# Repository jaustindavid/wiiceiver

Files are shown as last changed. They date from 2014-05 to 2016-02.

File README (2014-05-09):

http://austindavid.com/t/wiiceiver-github

The Wiiceiver is a drop-in "plug and play" replacement for a
standard R/C receiver.  It has a Nintendo Wii Nunchuck 
connection, a 3-pin ESC connector, and an available connector
for an external BEC if required.  

The Wiiceiver is intended for use on an electric skateboard.
The Y-axis (up/down) is throttle -- push up to speed up,
middle is neutral, down is brakes.  These function roughly
the same as on a standard RC transmitter.

Wiiceiver also implements a few additional functions:
- X/Y joystick axes, X/Y/Z accelerometers, and the two buttons 
  are monitored to confirm that the nunchuck is "active" -- 
  as opposed to dropped or low battery.  When "inactive" the
  wiiceiver returns to neutral, and will not re-start until 
  it detects and active neutral signal
- C button is "cruise control" -- press and hold C to maintain
  the current throttle level.  Drop the joystick to neutral to
  cruise.  While holding C, pressing the joystick "up" will
  increase speed gently, "down" will decrease speed.  
  Releasing C returns to neutral.
- Control smoothing: Wiiceiver implemenets an exponential 
  algorithm to smooth the controller input.  As currently
  tuned, an instant 0-100% throttle input will result in a
  gradual change to the ESC over the course of about 1s.

It has been tested to work with a corded Nintendo nunchuck, a 
Memorex wireless nunchuck, and a Nyko Kama wireless nunchuck.

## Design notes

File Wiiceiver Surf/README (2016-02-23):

Wiiceiver Surf Chuck + Wiiceiver Surf Board is a new *pair* of things.

The Chuck is a gutted / modified Nintendo Nunchuck w/ NRF24L01+ radio; 
it can run for hours on a small LiPo battery and has better range than
the Nyko Kama wireless.

The Board is an updated "Wiiceiver" with the NRF24L01+ radio hookup, 
but no traditional nunchuck port.

Board-side functionality is similar to the traditional Wiiceiver.
Over time I will add:
- voltage sensing on the Board / display to Chuck (red/green/yellow 
  lights to indicate battery remaining)
- integrated battery control: press a button on the Board to start it,
  use the Chuck power button to shut it down.
- pairing / syncing between up to 100 Chucks & 100 Boards

The fun thing about this setup: it doesn't depend on the Nintendo
Nunchuck; it can be easily integrated into any analog controller.

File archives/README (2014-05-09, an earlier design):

"archives" of Wiiceivers past

Wiiceiver_84 was based on the ATtiny84, a 14-pin Arduino-compatible
microcontroller.  It's significantly smaller than the ATmega328,
but doesn't have hardware support for I2C or PWM.  I successfully
emulated these in software (with significant help from available
libraries) but was having trouble with the Nyko Kama, and it can't 
present both Serial output as well as I2C and PWM -- hard to debug.
SN01 == Serial Number 1, it was soldered on hardware.  Works with 
a wired chuck, but see above re: debugging the Nyko.

Wiiceiver_85 was the same, but for ATtiny85: 8 pins, but otherwise
similar to the '84.

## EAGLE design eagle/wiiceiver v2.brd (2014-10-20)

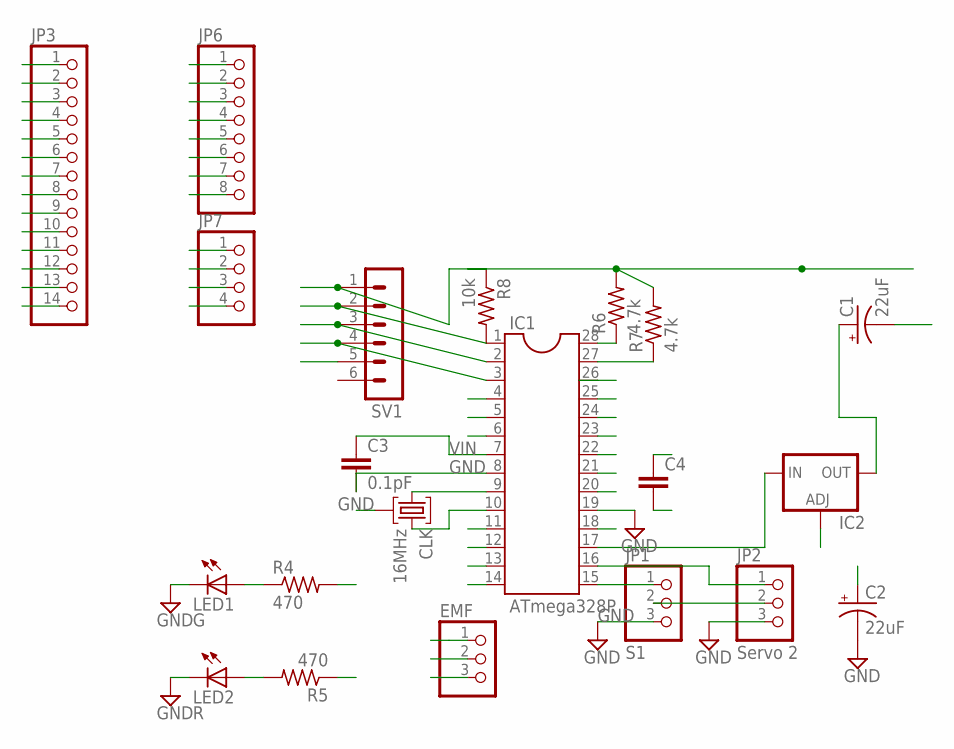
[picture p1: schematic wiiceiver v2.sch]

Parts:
C1, C2: 22uF; B45181A
C3: 0.1pF; C5B2.5
C4: C5/2.5; C5B2.5
CLK: 16MHz; HC49U
EMF: PINHD-1X3; 1X03
IC1: ATmega328P; DIL28-3
IC2: LM317TS; 317TS
JP1: S1; 1X03
JP2: Servo 2; 1X03
JP3: PINHD-1X14; 1X14
JP6: PINHD-1X8; 1X08
JP7: PINHD-1X4; 1X04
LED1: G; LED3MM
LED2: R; LED3MM
R4, R5: 470; 0204V
R6, R7: 4.7k; 0204V
R8: 10k; 0204V
SV1: MA06-1

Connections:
A0: IC1.23, JP3.6
A1: IC1.24, JP3.5
A2: IC1.25, JP3.4
A3: IC1.26, JP3.3
A4: IC1.27, JP3.2, R7.1
A5: IC1.28, JP3.1, R6.1
D0: IC1.2, JP6.2, SV1.3
D1: IC1.3, JP6.3, SV1.4
D2: IC1.4, JP6.4
D3: IC1.5, JP6.5
D4: IC1.6, JP6.6
D5: IC1.11, JP7.1
D6: IC1.12, JP7.2, R4.2
D7: IC1.13, JP7.3
D8: IC1.14, JP7.4, R5.1
D9: IC1.15, JP1.1, JP3.14
D10: IC1.16, JP2.1, JP3.13
D11: IC1.17, IC2.3 (IN), JP3.12
D12: IC1.18, JP3.11
D13: JP3.10
GND: C1.-, C2.-, C3.2, C4.2, CLK.2, EMF.2, IC1.8, IC1.19, IC1.22, IC2.1 (ADJ), JP1.3, JP2.3, JP3.7, JP6.8, LED1.K (C), LED2.K (C), SV1.5
unnamed: LED2.A, R5.2
unnamed: LED1.A, R4.1
unnamed: CLK.3, IC1.10
unnamed: CLK.1, IC1.9
unnamed: C1.+, IC2.2 (OUT)
RST: IC1.1, JP6.1, R8.2, SV1.2
VIN: C3.1, C4.1, EMF.3, IC1.7, IC1.20, IC1.21, JP3.8, JP3.9, JP6.7, R6.2, R7.2, R8.1, SV1.1
VRAW: C2.+, EMF.1, JP1.2, JP2.2

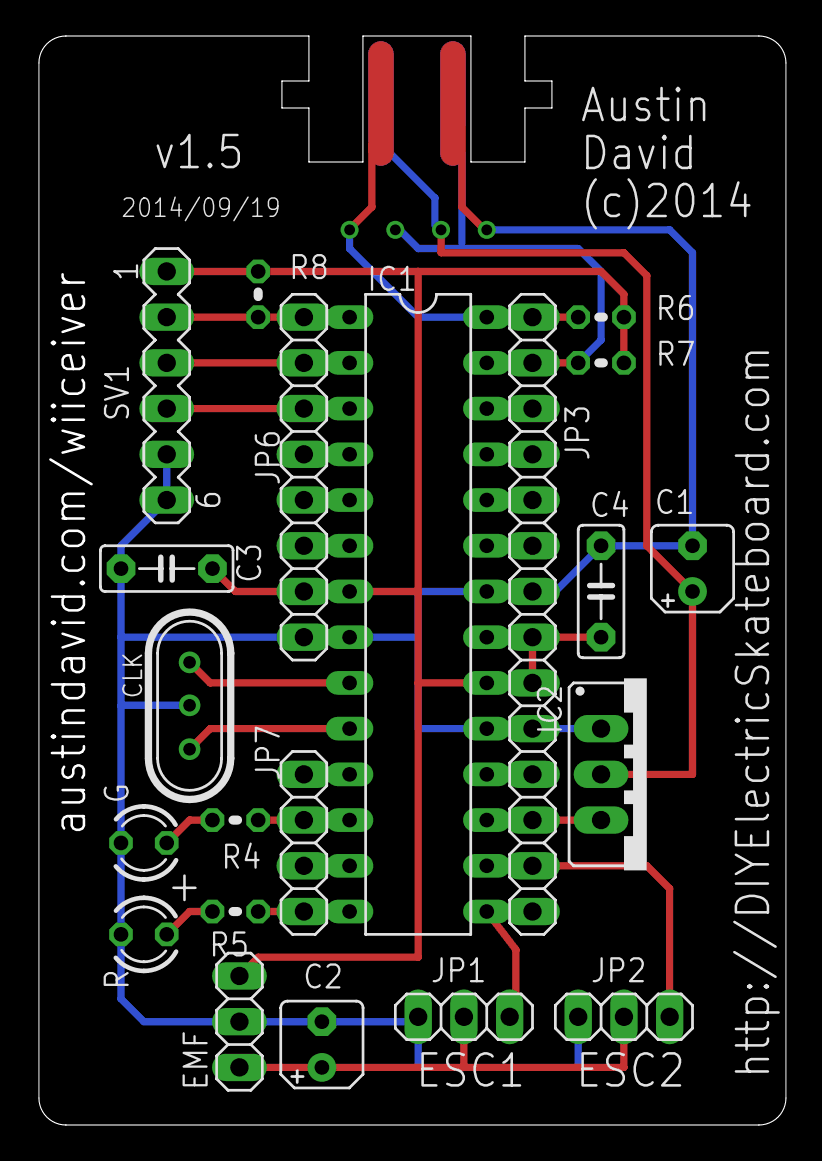
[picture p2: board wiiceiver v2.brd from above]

Board: 2 copper layers, 41.5 x 60.5 mm, 21 parts (0 on the bottom side), 28 nets.

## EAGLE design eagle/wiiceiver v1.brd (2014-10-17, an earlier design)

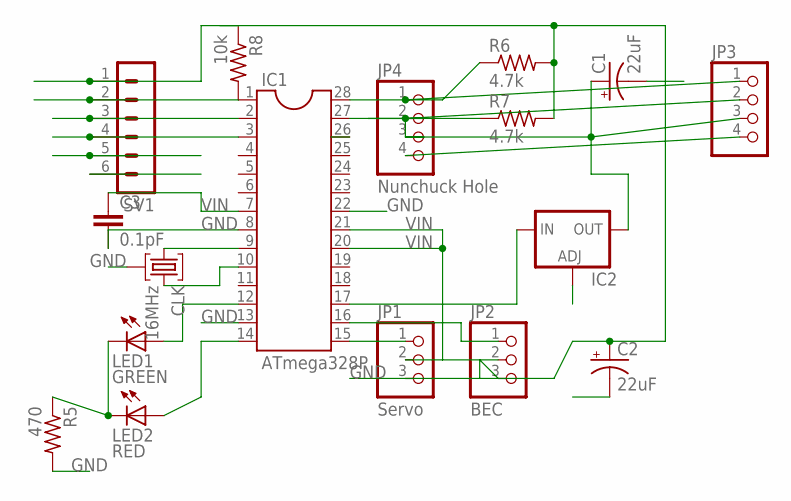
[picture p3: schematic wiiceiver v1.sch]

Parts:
C1, C2: 22uF; B45181A
C3: 0.1pF; C5B2.5
CLK: 16MHz; HC49U
IC1: ATmega328P; DIL28-3
IC2: LM317TS; 317TS
JP1: Servo; 1X03
JP2: BEC; 1X03
JP3: PINHD-1X4; 1X04
JP4: Nunchuck Hole; 1X04
LED1: GREEN; LED3MM
LED2: RED; LED3MM
R5: 470; 0204V
R6, R7: 4.7k; 0204V
R8: 10k; 0204V
SV1: MA06-1

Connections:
DIP12: IC1.12, LED1.A
GND: C1.-, C2.+, C2.-, C3.2, CLK.2, IC1.8, IC1.13, IC1.22, IC2.1 (ADJ), JP1.3, JP2.3, JP3.4, JP4.4, R5.2, R6.2, R7.2, R8.1, SV1.1, SV1.5, SV1.6
unnamed: IC1.15, JP1.1
unnamed: IC1.1, R8.2, SV1.2
unnamed: IC1.16, JP2.1
unnamed: LED1.K (C), LED2.K (C), R5.1
unnamed: IC1.14, LED2.A
unnamed: CLK.3, IC1.10
unnamed: IC1.17, IC2.3 (IN)
unnamed: CLK.1, IC1.9
unnamed: C1.+, IC2.2 (OUT), JP3.2, JP3.3, JP4.3
unnamed: IC1.28, JP3.1, JP4.1, R6.1
unnamed: IC1.27, JP4.2, R7.1
RX: IC1.2, SV1.3
TX: IC1.3, SV1.4
VIN: C3.1, IC1.7, IC1.20, IC1.21, JP1.2, JP2.2

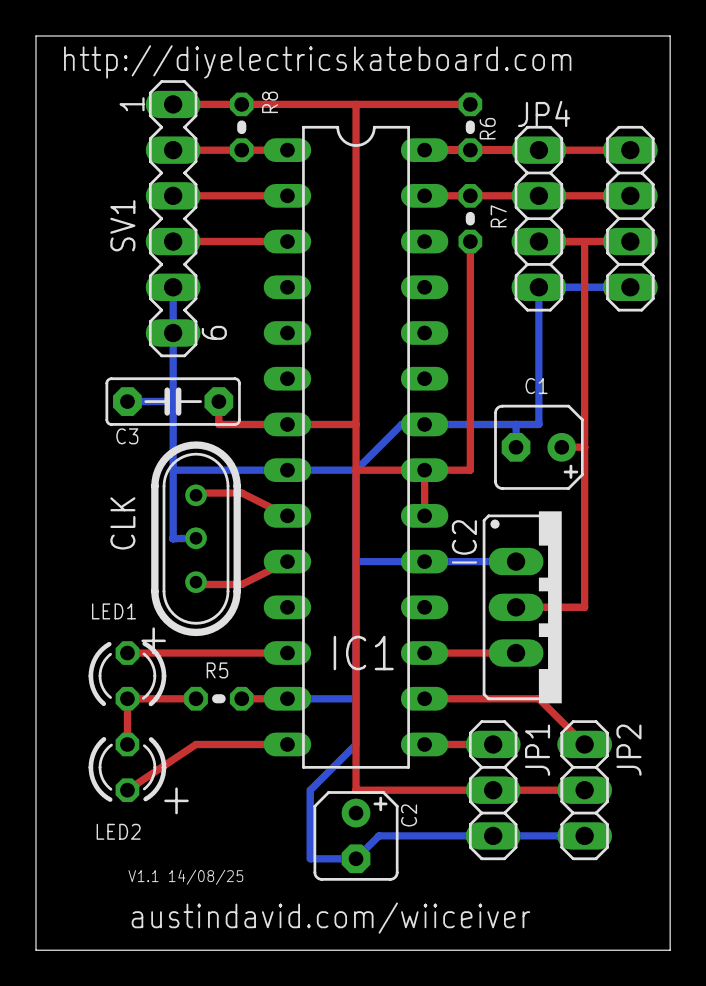
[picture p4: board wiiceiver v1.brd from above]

Board: 2 copper layers, 35.2 x 50.8 mm, 17 parts (0 on the bottom side), 16 nets.

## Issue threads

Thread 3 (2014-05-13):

faster ESC sync

jaustindavid, 2014-05-13:
wiiceiver should sync to the ESC faster.  It currently takes several seconds when the ESC is in "auto" mode.

jaustindavid, 2015-09-28:
2.0 improves flier sync

Closed 2016-05-17.

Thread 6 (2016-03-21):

can't make the motor spins correctly

shaohad, 2016-03-21:
i have this setup:
motor : turnigy 6364 213kv
battery pack 10s li-ion
esc - turnigy 120A HV - opto
wiiciver (purchased at diyelectricskateboard)
nyko nunchuk remote + usb dongle
5V battery pack instad of ubec

my issue: i benn tring all combinations , i manage to start the wiiciver , seems like it connected to remote.
but motor bips and wont spin when i press forward
i have connected same setup to simple servo tester and its working
any ideas?

jaustindavid, 2016-03-21:
What do the lights show when you start the wiiceiver?  How do you know it's connecting to the remote?

Were you able to run the setup routine?

shaohad, 2016-03-21:
how can we speak directly?
skype? so i could show you a video?
my email is shaohad@gmail.com

jaustindavid, 2016-03-21:
email the video to austin@austindavid.com

shaohad, 2016-03-21:
email sent

Closed 2016-05-17.

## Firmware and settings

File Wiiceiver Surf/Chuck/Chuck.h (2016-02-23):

/*
 * (CC BY-NC-SA 4.0) 
 * http://creativecommons.org/licenses/by-nc-sa/4.0/
 *
 * WARNING WARNING WARNING: attaching motors to a skateboard is 
 * a terribly dangerous thing to do.  This software is totally
 * for amusement and/or educational purposes.  Don't obtain or
 * make a wiiceiver (see below for instructions and parts), 
 * don't attach it to a skateboard, and CERTAINLY don't use it
 * to zip around with just a tiny, ergonomic nunchuck instead
 * of a bulky R/C controller.
 *
 * This software is made freely available.  If you wish to 
 * sell it, don't.  If you wish to modify it, DO! (and please
 * let me know).  Much of the code is derived from others out
 * there, I've made attributuions where appropriate.
 *
 * http://austindavid.com/wiiceiver
 *  
 * latest software: https://github.com/jaustindavid/wiiceiver
 * schematic & parts: http://www.digikey.com/schemeit#t9g
 *
 * Enjoy!  Be safe! 
 * 
 * (CC BY-NC-SA 4.0) Austin David, austin@austindavid.com
 * 12 May 2014
 *
 */
 
#ifndef CHUCK_H
#define CHUCK_H

/*
 *  A "tiny" Wii Nunchuck class
 *  Borrows heavily from:
 *
 *   Nunchuck -- Use a Wii Nunchuck
 *   Tim Hirzel http://www.growdown.com
 * who cites:
 *
 * * This file is an adaptation of the code by these authors:
 * Tod E. Kurt, http://todbot.com/blog/
 *
 * The Wii Nunchuck reading code is taken from Windmeadow Labs
 * http://www.windmeadow.com/node/42
 *
 * Conversion to Arduino 1.0 by Danjovic
 * http://hotbit.blogspot.com
 *
 * Included the Fix from Martin Peris by Leopold Klimesch
 * http://blog.martinperis.com/2011/04/arduino-wiichuck.html
 *
 *
 * Taking all of the above into account, this class is heavily adapted
 * for the specific usage here: a single-channel (~1.5), activity-sensitive 
 * controller for an electric skateboard.  I've deliberately removed or not used
 * a fair amount of the data available from the 'chuck, in the interest of 
 * keeping memory down for the ATtiny series.
 *
 */
class Chuck {
#ifndef WII_ACTIVITY_COUNTER
#define WII_ACTIVITY_COUNTER 250  // consecutive static reads & it's considered inactive
#endif
#define DEFAULT_Y_ZERO 128
#define DEFAULT_X_ZERO 128

private:
  byte lastStatus[6];
  byte Y0, Ymin, Ymax, X0, Xmin, Xmax;
  word lastActivity, activitySamenessCount;
public:
  byte status[6];
  float X, Y;
  bool C, Z;


private:

  bool all255s(void) {
    for (int i=0; i < 6; i++) {
      if (status[i] != 255) {
        return false;
      }
    }
    return true;
  } // bool all255s(void)


  bool statusChanged(void) {
    for (int i=0; i < 6; i++) {
      if (status[i] != lastStatus[i]) {
        return true;
      }
    }
    
    return false;
  } // bool statusChanged()
  
  
  void saveLastStatus(void) {
    for (int i=0; i < 6; i++) {
      lastStatus[i] = status[i];
    }
  } // void saveLastStatus()

  
  // tracks the max-observed deflection (high & low)
  void _selfCalibrateDeflection(void) {
    byte joyX = status[0];
    Xmin = min(joyX, Xmin);
    Xmax = max(joyX, Xmax);
 
    byte joyY = status[1];

    if (joyY < Ymin) {
      Ymin = joyY;
    }

    if (joyY > Ymax) {
      Ymax = joyY;
    }
  } // void _selfCalibrateDeflection(void)


  void _computeStatus(void) {
    byte joyX = status[0];
    byte joyY = status[1];
    _selfCalibrateDeflection();
    
    int centeredX = joyX - X0;
    if (centeredX == 0) {
      X = 0;
    } 
    else if (centeredX > 0) {
      X = 1.0 * centeredX / (Xmax - X0);
    } 
    else {
      X = -1.0 * centeredX / (Xmin - X0); 
    }
    
    int centeredY = joyY - Y0;
    if (centeredY == 0) {
      Y = 0;
    } 
    else if (centeredY > 0) {
      Y = 1.0 * centeredY / (Ymax - Y0);
    } 
    else {
      Y = -1.0 * centeredY / (Ymin - Y0); 
    }

    C = ((status[5] & B00000010) >> 1) == 0;
    Z = (status[5] & B00000001) == 0;


    if (!statusChanged()) { 
      if (activitySamenessCount < WII_ACTIVITY_COUNTER) {
        activitySamenessCount ++;
      }
    } else {
      activitySamenessCount = 0;
      saveLastStatus();
    }
    
#ifdef DEBUGGING_CHUCK_ACTIVITY
    Serial.print(F("CHUCK: "));
    for (int i = 0; i < 5; i++) {
      Serial.print(F(" ["));
      Serial.print(status[i], DEC);
      Serial.print(F("]"));
    }
    Serial.print(F("; sameness "));
    Serial.print(activitySamenessCount);    
    Serial.println();
#endif


  } // _computeStatus(void)


public:


  void calibrateCenter() {
    Y0 = status[1];
  } // calibrateCenter()


  // setup the nunchuck -- send the initialization sequence & start reading data
  void setup(void) {
    X0 = Y0 = 128;
    Xmin = Ymin = 15;
    Xmax = Ymax = 200;

#ifdef DEBUGGING_CHUCK
    Serial.print(millis());
    Serial.print(F(": Chuck.setup() ..."));
#endif
    Wire.begin();
    Wire.beginTransmission(0x52);       // device address
    Wire.write(0xF0);
    Wire.write(0x55);
    Wire.endTransmission();
    delay(1);
    Wire.beginTransmission(0x52);
    Wire.write(0xFB);
    Wire.write((uint8_t)0x00);
    Wire.endTransmission();
#ifdef DEBUGGING_CHUCK
    Serial.print(F(" transmitted @ "));
    Serial.print(millis());
#endif

    // do enough updates to prime the activity checker ...
    for (int i = 0; i < WII_ACTIVITY_COUNTER; i++) {
      update();
      delay(1);
    }
    
 #ifdef DEBUGGING_CHUCK
    Serial.print(F("; setup complete @ "));
    Serial.println(millis());
#endif   
  } // void setup(void)


  // update the status[] fields from the nunchuck
  void update(void) {
    // TODO: estimate the actual delay required between the request 
    // & data available on bus
    // delay(1);

    // read 6 bytes
    Wire.requestFrom (0x52, 6); // request data from nunchuck
    int cnt = 0;
    while (Wire.available()) {
      status[cnt] = Wire.read();
      cnt++;
    }

    _computeStatus();
#ifdef DEBUGGING_CHUCK_ACTIVITY
   Serial.print(F("Active? "));
   Serial.println(isActive() ? F("yes") : F("no"));
#endif

    // send one 0 to initiate transfer
    Wire.beginTransmission(0x52); 
    Wire.write(0);         
    Wire.endTransmission();

  } // void update(void)


  // is the controller "active" -- being held by a human & reporting
  // changing values?
  bool isActive(void) {
    return activitySamenessCount < WII_ACTIVITY_COUNTER && ! all255s();
  } // bool isActive(void)

};

#endif

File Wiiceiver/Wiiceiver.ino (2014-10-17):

/*
 * (CC BY-NC-SA 4.0) 
 * http://creativecommons.org/licenses/by-nc-sa/4.0/
 *
 * WARNING WARNING WARNING: attaching motors to a skateboard is 
 * a terribly dangerous thing to do.  This software is totally
 * for amusement and/or educational purposes.  Don't obtain or
 * make a wiiceiver (see below for instructions and parts), 
 * don't attach it to a skateboard, and CERTAINLY don't use it
 * to zip around with just a tiny, ergonomic nunchuck instead
 * of a bulky R/C controller.
 *
 * This software is made freely available.  If you wish to 
 * sell it, don't.  If you wish to modify it, DO! (and please
 * let me know).  Much of the code is derived from others out
 * there, I've made attributuions where appropriate.
 *
 * http://austindavid.com/wiiceiver
 *  
 * latest software: https://github.com/jaustindavid/wiiceiver
 * schematic & parts: http://www.digikey.com/schemeit#t9g
 *
 * Enjoy!  Be safe! 
 * 
 * (CC BY-NC-SA 4.0) Austin David, austin@austindavid.com
 * 12 May 2014
 *
 */

#include <avr/wdt.h> 
#include <Wire.h>
#include <Servo.h>
#include <EEPROM.h>

#define WIICEIVER_VERSION "1.2.2"

// addys for vars stored in EEPROM
#define EEPROM_Y_ADDY 0
#define EEPROM_AUTOCRUISE_ADDY 1
#define EEPROM_WDC_ADDY 2


#define DEBUGGING

#include "Blinker.h"


// #define DEBUGGING_CHUCK
// #define DEBUGGING_CHUCK_ACTIVITY
#define WII_ACTIVITY_COUNTER 100  // once per 20ms; 50 per second
#include "Chuck.h"


// #define DEBUGGING_ESC
#include "ElectronicSpeedController.h"


// #define DEBUGGING_SMOOTHER
#define SMOOTHER_MIN_STEP 0.003           // minimum change for smoothing; 0.003 for ~1s, 0.001 for ~2s
#define SMOOTHER_BRAKES_PROGRAM 0
#define SMOOTHER_THROTTLE_PROGRAM 1
#define SMOOTHER_THROTTLE_Z_PROGRAM 2
#define SMOOTHER_CRUISE_RESUME_PROGRAM 3
#include "Smoother.h"


// #define DEBUGGING_THROTTLE
#define THROTTLE_MIN 0.05                      // the lowest throttle to send the ESC
#define THROTTLE_CC_BUMP 0.003                 // CC = 0.2% throttle increase; 50/s = 10s to hit 100% on cruise
#define THROTTLE_MIN_CC 0.05                   // minimum / inital speed for cruise crontrol
                                               // note that a different value may be stored in EEPROM
#define THROTTLE_CRUISE_RETURN_MS 5000         // time (ms) when re-grabbing cruise will use the previous CC level
#include "Throttle.h"


// #define DEBUGGING_PINS
#include "pinouts.h"


Chuck chuck;
ElectronicSpeedController ESC;
Blinker green, red;
Throttle throttle;


/********
 *  WATCHDOG STUFF
 * I referenced the following:
 * http://forum.arduino.cc/index.php?topic=63651.0
 * http://tushev.org/articles/arduino/item/46-arduino-and-watchdog-timer
 * http://www.ivoidwarranties.com/2012/02/arduino-mega-optiboot.html
 *
 ********/
 
/*
 * setup a watchdog timer for the given reset interval
 *
 * constants: WDTO_250MS, WDTO_8S, WDTO_60MS, etc
 */
void watchdog_setup(byte wd_interval) {
  wdt_reset();
  wdt_enable(wd_interval);
  cli();
  WDTCSR |= (1<<WDCE) | (1<<WDE) | (1<<WDIE); 
  sei();
} // watchdog_setup(unsigned int wd_interval)


// increment a _W_atch _D_og _C_ounter stored in EEPROM, for future debugging
ISR(WDT_vect) {
  byte wdt_counter = EEPROM.read(EEPROM_WDC_ADDY);
  EEPROM.write(EEPROM_WDC_ADDY, wdt_counter + 1);
} // ISR for the watchdog timer

// display the current watchdog counter
void display_WDC(void) {
  byte wdt_counter = EEPROM.read(EEPROM_WDC_ADDY);
  Serial.print("Watchdog Resets: ");
  Serial.println((byte)(wdt_counter + 1));
} // display_WDC()



// maybe calibrate the joystick:
//   read the C button 250 times, once per 20ms (5s total); if it's constantly
//   down, calibrate the joystick
void maybeCalibrate(void) {
  int ctr = 0;
  int i = 0;

  for (i = 0; i < 10; i++) {
    chuck.update();
    delay(10);
  }
  if (chuck.C != 1 || ! chuck.isActive()) {
    return;
  }

  red.update(10);
  green.update(10);
  i = 0;
  #define C_COUNT 50
  while (i <= C_COUNT && chuck.C) {
    chuck.update();
    red.run();
    green.run();
    i++;
    ctr += chuck.C;
    delay(20);
  }

  #ifdef DEBUGGING
  Serial.print("C ctr = ");
  Serial.println(ctr);
  #endif

  if (ctr >= C_COUNT && chuck.isActive()) {
    chuck.calibrateCenter();
    chuck.writeEEPROM();
    // side effect: reset the WDC
    EEPROM.write(EEPROM_WDC_ADDY, 255);
    Serial.println("Calibrated");
  }

  red.update(1);
  green.update(1);
} // void maybeCalibrate() 

\
// an unambiguous startup display
void splashScreen() {
  int i;
  digitalWrite(pinLocation(GREEN_LED_ID), HIGH);
  digitalWrite(pinLocation(RED_LED_ID), HIGH);
  delay(250);
  for (i = 0; i < 5; i++) {
    digitalWrite(pinLocation(GREEN_LED_ID), HIGH);
    digitalWrite(pinLocation(RED_LED_ID), LOW);
    delay(50);
    digitalWrite(pinLocation(GREEN_LED_ID), LOW);
    digitalWrite(pinLocation(RED_LED_ID), HIGH);
    delay(50);
  }
  digitalWrite(pinLocation(GREEN_LED_ID), HIGH);
  digitalWrite(pinLocation(RED_LED_ID), HIGH);
  delay(250);
  digitalWrite(pinLocation(GREEN_LED_ID), LOW);    
  digitalWrite(pinLocation(RED_LED_ID), LOW);  
} // void splashScreen(void)


// flash the LEDs to indicate throttle position
void updateLEDs(Throttle throttle) {
  if (throttle.getThrottle() == 0) {
    green.update(1);
    red.update(1);
  } else {
    int bps = abs(int(throttle.getThrottle() * 20));

    if (throttle.getThrottle() > 0) {
      green.update(bps);
      red.update(1);
    } else {
      green.update(1);
      red.update(bps);
    }
  }
} // updateLEDs(float throttle)


// the nunchuck appears to be static: we lost connection!
// go "dead" for up to 5s, but keep checking the chuck to see if
// it comes back
void freakOut(void) {
  unsigned long targetMS = millis() + 5000;
  bool redOn = false;
  byte blinkCtr = 0;

#ifdef DEBUGGING
    Serial.print(millis());
    Serial.println(": freaking out");
#endif

  red.stop();
  green.stop();
  while (!chuck.isActive() && targetMS > millis()) {
//  while (targetMS > millis()) {
    if (blinkCtr >= 4) {
      blinkCtr = 0;
      if (redOn) {
        red.high();
        green.low();
        redOn = false;
      } 
      else {
        red.low();
        green.high();
        redOn = true;
      }
    }
    blinkCtr ++;
    chuck.update();
    delay(20);
    wdt_reset();
  }
  green.start(1);
  red.start(1);
} // void freakOut(void)



void setup_pins() {
  /*
  pinMode(ESC_GROUND, OUTPUT);
  digitalWrite(ESC_GROUND, LOW);
  pinMode(WII_GROUND, OUTPUT);
  digitalWrite(WII_GROUND, LOW);
  */
  pinMode(pinLocation(WII_POWER_ID), OUTPUT);
  digitalWrite(pinLocation(WII_POWER_ID), HIGH);
  
  pinMode(pinLocation(WII_SCL_ID), INPUT_PULLUP);
  pinMode(pinLocation(WII_SDA_ID), INPUT_PULLUP);

} // setup_pins()


// wait up to 1s for something to happen
bool waitForActivity(void) {
  unsigned long timer = millis() + 1000;
#ifdef DEBUGGING
    Serial.print(millis());
    Serial.print(" Waiting for activity ... ");
#endif
  
  chuck.update();
  while (! chuck.isActive() && timer > millis()) {
    wdt_reset();
    delay(20);
    chuck.update();
  }
#ifdef DEBUGGING
    Serial.print(millis());
    Serial.println(chuck.isActive() ? ": active!" : ": not active :(");
#endif
  
  return chuck.isActive();
} // bool waitForActivity()


// dead code?
void stopChuck() {
#ifdef DEBUGGING
    Serial.println("Nunchuck: power off");
#endif
  digitalWrite(pinLocation(WII_POWER_ID), LOW);
  delay(250);
#ifdef DEBUGGING
    Serial.println("Nunchuck: power on");
#endif
  digitalWrite(pinLocation(WII_POWER_ID), HIGH);
  delay(250);
} // stopChuck()



// returns true if the chuck appears "active"
// will retry 5 times, waiting 1s each
bool startChuck() {
  int tries = 0;
  
  while (tries < 10) {
#ifdef DEBUGGING
    Serial.print("(Re)starting the nunchuck: #");
    Serial.println(tries);
#endif
    wdt_reset();
    chuck.setup();
    chuck.readEEPROM();
    tries ++;
    if (waitForActivity()) {
      return true;
    }
  }
  return false;
} // startChuck()


// pretty much what it sounds like
void handleInactivity() {
  watchdog_setup(WDTO_8S);
#ifdef DEBUGGING
  Serial.print(millis());
  Serial.println(": handling inactivity");
#endif
  // lastThrottle = 0; // kills cruise control
  // smoother.zero();  // kills throttle history
  throttle.zero();
  ESC.setLevel(0);
  
  // this loop: try to restart 5 times in 5s; repeat until active
  do {    
    freakOut();
    if (! chuck.isActive()) {
      // stopChuck();
      // delay(250);
      startChuck();
    }
  } while (! chuck.isActive());
  
  // active -- now wait for zero
#ifdef DEBUGGING
  Serial.print(millis());
  Serial.println("Waiting for 0");
#endif  
  while (chuck.Y > 0.1 || chuck.Y < -0.1) {
    chuck.update();
    wdt_reset();
    delay(20);
  }
  
#ifdef DEBUGGING
  Serial.print(millis());
  Serial.println(": finished inactivity -- chuck is active");
#endif
  watchdog_setup(WDTO_250MS);
} // handleInactivity()




void setup() {
  wdt_disable();
  Serial.begin(115200);

  Serial.print("Wiiceiver v ");
  Serial.print(WIICEIVER_VERSION);
  Serial.print(" (compiled ");
  Serial.print(__DATE__);
  Serial.print(" ");
  Serial.print(__TIME__);
  Serial.println(")");
  display_WDC();
  
  green.init(pinLocation(GREEN_LED_ID));
  red.init(pinLocation(RED_LED_ID));

  setup_pins();
  ESC.init(pinLocation(ESC_PPM_ID), pinLocation(ESC2_PPM_ID));
  
  splashScreen();

  // delay(5000); // hold for nunchuck powerup

#ifdef DEBUGGING
  Serial.println("Starting the nunchuck ...");
#endif
  green.high();
  red.high();
  if (startChuck()) {
    maybeCalibrate();
  } else {
    handleInactivity();
  }
#ifdef DEBUGGING
  Serial.println("Nunchuck is active!");
#endif

  throttle.init();

  green.start(10);
  red.start(10);
  
  green.update(1);
  red.update(1);
  watchdog_setup(WDTO_250MS);
} // void setup()



void loop() {
  static float lastThrottleValue = 0;
  unsigned long startMS = millis();
  wdt_reset();
  green.run();
  red.run();
  chuck.update();
  
  // for forcing a watchdog timeout
  #undef SUICIDAL_Z
  #ifdef SUICIDAL_Z
  if (chuck.Z) {
    Serial.println("sleepin' to reset");
    delay(9000);
  } // suicide!
  
  
  #endif 
  if (!chuck.isActive()) {
#ifdef DEBUGGING
    Serial.println("INACTIVE!!");
#endif
    handleInactivity();
  } else {
    float throttleValue = throttle.update(chuck);
    ESC.setLevel(throttleValue);
    if (throttleValue != lastThrottleValue) {
      updateLEDs(throttle);
#ifdef DEBUGGING
      Serial.print("y=");
      Serial.print(chuck.Y, 4);
      Serial.print(", ");
      Serial.print("c=");
      Serial.print(chuck.C);      
      Serial.print(", z=");
      Serial.print(chuck.Z);
      Serial.print(", ");
      Serial.println(throttleValue, 4); 
#endif
      lastThrottleValue = throttleValue;
    }
    int delayMS = constrain(startMS + 21 - millis(), 5, 20);
#ifdef DEBUGGING_INTERVALS
    Serial.print("sleeping "); 
    Serial.println(delayMS);
#endif
    delay(delayMS);
  } // if (chuck.isActive())
}

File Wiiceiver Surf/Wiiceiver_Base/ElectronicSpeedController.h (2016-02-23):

/*
 * (CC BY-NC-SA 4.0) 
 * http://creativecommons.org/licenses/by-nc-sa/4.0/
 *
 * WARNING WARNING WARNING: attaching motors to a skateboard is 
 * a terribly dangerous thing to do.  This software is totally
 * for amusement and/or educational purposes.  Don't obtain or
 * make a wiiceiver (see below for instructions and parts), 
 * don't attach it to a skateboard, and CERTAINLY don't use it
 * to zip around with just a tiny, ergonomic nunchuck instead
 * of a bulky R/C controller.
 *
 * This software is made freely available.  If you wish to 
 * sell it, don't.  If you wish to modify it, DO! (and please
 * let me know).  Much of the code is derived from others out
 * there, I've made attributuions where appropriate.
 *
 * http://austindavid.com/wiiceiver
 *  
 * latest software: https://github.com/jaustindavid/wiiceiver
 * schematic & parts: http://www.digikey.com/schemeit#t9g
 *
 * Enjoy!  Be safe! 
 * 
 * (CC BY-NC-SA 4.0) Austin David, austin@austindavid.com
 * 12 May 2014
 *
 */

#ifndef ELECTRONICSPEEDCONTROLLER_H
#define ELECTRONICSPEEDCONTROLLER_H

/*
 *    ESC wrapper class
 */

class ElectronicSpeedController {
#define ESC_CENTER 90       // angle of the "center"; probably always 90
#define ESC_MAX_ANGLE 180   // angle of "max" deflection


private:
  bool dualESC;
  SoftwareServo _esc1, _esc2;
  int angle;                // the angle most recently written to _esc;
  int angleCtr;
  int microseconds;         // the time (ms) most recently written
  unsigned long lastWrite;  // time in millis() when it was last written

public:

  void init(int pin1, int pin2) {
    angle = -1;
    angleCtr = 0;
    lastWrite = 0;
    #ifdef DEBUGGING_ESC
      Serial.print("attaching to pin1 #");
      Serial.println(pin1);
      Serial.print(", pin2 #");
      Serial.print(pin2);
    #endif
    _esc1.attach(pin1);
    if (pin2) {
      dualESC = true;
      _esc2.attach(pin2);
      Serial.println("Dual ESC!");
    } else {
      dualESC = false;
    }
    
    
    delay(21);  // give the "last written" protection room to work
    #ifdef DEBUGGING
      Serial.println("initializing ESC...");
    #endif
  
    // syncESC();
    // calibrateESC();
    // sync2();
    sync3();
    setLevel(0);
    
    #ifdef DEBUGGING
      Serial.println("done");
    #endif
  } // void init(int pin)


  /*
   * input: -1 .. 1
   * output: writes +/- ESC_MAX_ANGLE to _esc
   * does *not* write the same angle twice -- possible interference with the PWM :(
   * Servo will continually pulse the last-written angle anyway
   * 
   * HELI_ESC: 
   *   -1 .. 0 => angle 0
   *    0 .. 1 => angle 0 .. 180
   */
  void setLevel(float level) {  
    int newAngle = (int)(ESC_CENTER + (ESC_MAX_ANGLE - ESC_CENTER) * level);
    #ifdef ALLOW_HELI_MODE
      if (settings.HELI_MODE) {
        if (level <= 0) {
          newAngle = 0;
        } else {
          newAngle = (int)(ESC_MAX_ANGLE * level);
        }
      }
    #endif

    if (newAngle != angle) {
      #ifdef DEBUGGING_ESC
        Serial.print(millis());
        Serial.print(F(": ESC old: "));
        // Serial.print(_esc1.readMicroseconds());
        Serial.print(F("us; new angle: "));
        Serial.print(newAngle);
        Serial.print(F(" = "));
      #endif
      angle = newAngle;
      angleCtr = 0;
      _esc1.write(angle);
      if (dualESC) {
        _esc2.write(angle);
      }
      #ifdef DEBUGGING_ESC
          //Serial.print(F(": ESC now: "));
          //Serial.println(_esc1.readMicroseconds());
      #endif
      
      lastWrite = millis();
      /*
    } else {
      
      if (angleCtr++ > 10) {
        setLevel(level + 0.01);
      }
      */
    }
  } // void setLevel(float level)


private:

/* DEAD CODE
#define STEP_DELAY 20
#define SYNC_LIMIT 0.6

  void sweep(float startLevel, float endLevel, float step) {
#ifdef DEBUGGING_ESC
    Serial.print("sweep: ");
    Serial.print(startLevel);
    Serial.print(" to ");
    Serial.print(endLevel);
    Serial.print(" by ");
    Serial.println(step);
#endif
    for (float level = startLevel; level != endLevel; level += step) {
      setLevel(level);
      delay(STEP_DELAY);
    }
    setLevel(endLevel);
  } // sweep(float startLevel, float endLevel, float step)
*/

  // http://electronics.stackexchange.com/questions/24826/activating-electronic-speed-control-with-arduino  
  // startup sequence: some small range of inputs, then idle
  void syncESC(void) {
    setLevel(0);
    delay(100);
    setLevel(1);
    delay(50);
    setLevel(-1);
    delay(50);
    setLevel(0);
    delay(100);
    setLevel(1);
    delay(100);
    setLevel(0);
    delay(100);
  } // void syncESC(void)
  
  void sync2(void) {
    setLevel(-1);
    delay(3000);
    setLevel(0);
  }
  
  void sync3(void) {
    setLevel(1);
    delay(500);
    setLevel(-1);
    delay(500);
    setLevel(0);
  }
  
  void calibrateESC(void) {
    setLevel(1);
    delay(2000);
    setLevel(-1);
    delay(1000);
    setLevel(0);
  }
};  // class ElectronicSpeedController 

#endif

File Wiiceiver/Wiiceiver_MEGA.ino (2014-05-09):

#include <Wire.h>
#include <Servo.h>
#include <EEPROM.h>

#include "Blinker.h"

// #define DEBUGGING_SMOOTHER
#include "Smoother.h"

// #define DEBUGGING_CHUCK
// #define DEBUGGING_CHUCK_ACTIVITY
#define WII_ACTIVITY_COUNTER 100  // once per 20ms; 50 per second
#include "Chuck.h"

#define DEBUGGING_ESC
#include "ElectronicSpeedController.h"

#define DEBUGGING

/*
 * Wiiceiver hardware definitions
 * don't change these without changing the board 
 */
#define GREEN_LED 7   // any digital pin; DIP13
#define RED_LED 8     // any digital pin; DIP14

#define ESC_PPM 10    // PWM required; DIP16
#define ESC_GROUND 00 // hard-wired

#define WII_SCL 19    // aka A5 -- DO NOT USE  (Wire needs it)
#define WII_SDA 18    // aka A4 -- DO NOT USE  (Wire needs it)
#define WII_POWER 9   // any digital pin; DIP15
#define WII_GROUND 00 // hard-wired




Chuck chuck = Chuck();
ElectronicSpeedController ESC;
Blinker green = Blinker(GREEN_LED);
Blinker red = Blinker(RED_LED);
Smoother smoother = Smoother(0.2);


// maybe calibrate the joystick:
//   read the C button 50 times, once per 100ms (5s total); if it's constantly
//   down, calibrate the joystick
void maybeCalibrate(void) {
  int ctr = 0;
  int i = 0;

  chuck.update();
  while (i < 250 && chuck.C) {
    chuck.update();
    red.run();
    green.run();
    i++;
    ctr += chuck.C;
    delay(20);
  }

#ifdef DEBUGGING  
  Serial.print("C = ");
  Serial.println(ctr);
#endif

  if (chuck.C == 1 && chuck.isActive()) {
    chuck.calibrateCenter();
    chuck.writeEEPROM();
#ifdef DEBUGGING
    Serial.println("Calibrated");
#endif
  }

  red.update(1);
  green.update(1);
}


// an unambiguous startup display
void splashScreen() {
  int i;
  digitalWrite(GREEN_LED, HIGH);
  digitalWrite(RED_LED, HIGH);
  delay(500);
  for (i = 0; i < 10; i++) {
    digitalWrite(GREEN_LED, HIGH);
    digitalWrite(RED_LED, LOW);
    delay(50);
    digitalWrite(GREEN_LED, LOW);
    digitalWrite(RED_LED, HIGH);
    delay(50);
  }
  digitalWrite(GREEN_LED, HIGH);
  digitalWrite(RED_LED, HIGH);
  delay(500);
  digitalWrite(GREEN_LED, LOW);    
  digitalWrite(RED_LED, LOW);  
} // void splashScreen(void)


// flash the LEDs to indicate throttle position
void updateLEDs(float throttle) {
  if (throttle == 0) {
    green.update(1);
    red.update(1);
  } else {
    int bps = abs(int(throttle * 20));

    if (throttle > 0) {
      green.update(bps);
      red.update(1);
    } else {
      green.update(1);
      red.update(bps);
    }
  }
} // updateLEDs(float throttle)


// the nunchuck appears to be static: we lost connection!
// go "dead" for up to 5s, but keep checking the chuck to see if
// it comes back
void freakOut(void) {
  unsigned long targetMS = millis() + 5000;
  bool redOn = false;
  byte blinkCtr = 0;

#ifdef DEBUGGING
    Serial.print(millis());
    Serial.println(": freaking out");
#endif

  red.stop();
  green.stop();
  while (!chuck.isActive() && targetMS > millis()) {
//  while (targetMS > millis()) {
    if (blinkCtr >= 4) {
      blinkCtr = 0;
      if (redOn) {
        red.high();
        green.low();
        redOn = false;
      } 
      else {
        red.low();
        green.high();
        redOn = true;
      }
    }
    blinkCtr ++;
    chuck.update();
    delay(20);
  }
  green.start(1);
  red.start(1);
} // void freakOut(void)



void setup_pins() {
  /*
  pinMode(ESC_GROUND, OUTPUT);
  digitalWrite(ESC_GROUND, LOW);
  pinMode(WII_GROUND, OUTPUT);
  digitalWrite(WII_GROUND, LOW);
  */
  pinMode(WII_POWER, OUTPUT);
  digitalWrite(WII_POWER, HIGH);
} // setup_pins()



// dead code
void stopChuck() {
#ifdef DEBUGGING
    Serial.println("Nunchuck: power off");
#endif
  digitalWrite(WII_POWER, LOW);
  delay(250);
#ifdef DEBUGGING
    Serial.println("Nunchuck: power on");
#endif
digitalWrite(WII_POWER, HIGH);
  delay(5000);
} // stopChuck()


// returns true if the chuck appears "active"
bool startChuck() {
  int tries = 0;
  
  while (tries < 5) {
#ifdef DEBUGGING
    Serial.println("(Re)starting the nunchuck");
#endif
    chuck.setup();
    tries ++;
    if (chuck.isActive()) {
      return true;
    }
  }
  return false;
} // startChuck()



#define MIN_THROTTLE 0.05 // the lowest throttle to send the ESC
#define THROTTLE_CC_BUMP 0.001 // CC = 0.1% throttle increase; 50/s = 10s to hit 100% on cruise
float lastThrottle = 0;
float getThrottle() {
  float throttle;

#ifdef DEBUGGING
    Serial.print("Throttle ");
#endif

  if (chuck.C) { // cruise control!
#ifdef DEBUGGING
    Serial.print("CC: last = ");
    Serial.print(lastThrottle);
    Serial.print(", ");
#endif
    throttle = lastThrottle;
    if (chuck.Y > 0.5 && throttle < 1.0) {
      throttle += THROTTLE_CC_BUMP;
    } else if (chuck.Y < -0.5 && throttle > -1.0) {
      throttle -= THROTTLE_CC_BUMP;
    } 
      
  } else {
    throttle = chuck.Y;

    if (abs(throttle) < MIN_THROTTLE) {
      throttle = 0;
    }
  }

#ifdef DEBUGGING
    Serial.print("setting ");
    Serial.println(throttle);
#endif
  
  lastThrottle = throttle;
  return smoother.compute(throttle);
} // float getThrottle()



void handleInactivity() {
#ifdef DEBUGGING
  Serial.print(millis());
  Serial.println(": handling inactivity");
#endif
  lastThrottle = 0; // kills cruise control
  smoother.zero();  // kills throttle history
  ESC.setLevel(0);
  do {    
    freakOut();
    if (! chuck.isActive()) {
      // stopChuck();
      // delay(250);
      startChuck();
    }
  } while (! chuck.isActive());
  
  // active -- now wait for zero
#ifdef DEBUGGING
  Serial.print(millis());
  Serial.println("Waiting for 0");
#endif  
  while (chuck.Y > 0.1 || chuck.Y < -0.1) {
    chuck.update();
    delay(20);
  }
  
#ifdef DEBUGGING
  Serial.print(millis());
  Serial.println(": finished inactivity -- chuck is active");
#endif  

} // handleInactivity()


void setup() {
  Serial.begin(115200);
#ifdef DEBUGGING
  Serial.print("Wiiceiver (");
  Serial.print(__DATE__);
  Serial.print(" ");
  Serial.print(__TIME__);
  Serial.println(") starting");
#endif

  green.init();
  red.init();

  setup_pins();
  splashScreen();
  
  delay(5000); // hold for nunchuck powerup

#ifdef DEBUGGING
  Serial.println("Starting the nunchuck ...");
#endif
  green.high();
  red.high();
  if (! startChuck()) {
    handleInactivity();
  }
#ifdef DEBUGGING
  Serial.println("Nunchuck is active!");
#endif

  green.start(10);
  red.start(10);
  
  green.update(1);
  red.update(1);
  
  ESC.init(ESC_PPM);
} // void setup()
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

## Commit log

2014-05-09 archives: alternate parts
    implementations of an ATtiny84- and ATtiny85-based wiiceiver. These
    were the first two produced units, but were abandoned due to
    development and debugging problems.
    [Wiiceiver_84_SN01.ino, Wiiceiver_85.ino]
2014-05-09 Working ATmega328-based Wiiceiver code
    “production” code for the ATmega328-based hardware
2014-05-10 fixing issue with over-updating ESC
    inadvertently in
    [Wiiceiver.ino]
2014-05-10 ignoring the local tool
    just a tool to copy from the Arduino working environment into the git
    repo
2014-05-10 re-adding calibration on startup
    re-added the older calibrate-on-startup code
    also cleaned up some debugging statements in Chuck.h leftover from a
    previous refactor
2014-05-10 refactoring throttle
    … adds buttery smoothness
2014-05-11 v1 layout change; initial cruise
    v1 board has a slightly different layout; adding a runtime
    board-detection algorithm & pin mapping.
    Also adds minimum / initial cruise control — holding C at startup or
    very low speeds will accelerate to the specified minimum (currently
    0.10 == 10%)
2014-05-12 autoCruise !!
    a default 10%, configurable “autoCruise” level.
2014-05-16 eagle schematics
    Schematics / layout of the wiiceiver v1 hardware
    [wiiceiver v1.brd, wiiceiver v1.sch]
2014-05-17 re-grab cruise; better brakes -> throttle
    re-grab cruise: if you drop cruise and idle (no stick input) for fewer
    than 5 seconds, hitting C will return the previous cruise speed. Time
    is configurable with THROTTLE_CRUISE_RETURN_MS
    brakes->throttle: previously the return from braking to neutral was
    “smoothed” — hitting brakes & letting go is a gradual let-go. That’s
    fixed now, it lets go of brakes immediately.
    [ElectronicSpeedController.h, Throttle.h, Wiiceiver.ino]
2014-05-17 recording the time we last changed the ESC
2014-05-19 don't smooth brakes
    braking (and releasing) is now unsmoothed, totally responsive.
2014-05-20 better brake-smoothing
2014-05-22 ordered!
    “final” version, ordered from OshPark
    [wiiceiver v1.brd, wiiceiver v1.sch]
2014-05-24 A fix to live-restart the Kama
    Nyko Kama is sorta weird about getting restarted. This might fix it.
    The memorex + hardwired chuck both still work also.
    [Chuck.h, Wiiceiver.ino]
2014-05-24 more gently restarting the Kama
    Kama will crash the I2C bus on hard restart, so we don’t do that
    anymore. A few live re-inits seem to be enough (while bench-testing)
    [Chuck.h, Wiiceiver.ino]
2014-05-25 fine-tuning the Servo
    now forcing Servo to 1000/2000ms, adding debug output to confirm the
    actual pulse width, putting the angles out to 0/180, and tinkering with
    the ESC initialization sequence.
    ESC still doesn’t initialize quickly, but everything else tests fine.
    [ElectronicSpeedController.h, Wiiceiver.ino]
2014-05-25 fixing ESC sync?
2014-05-26 "Beta" release candidate
    Includes fixes for all known issues
    * Fast (perfect?) ESC sync
    * fast / continuous Kama restart
    * ESCs exactly 1000-2000us, midpoint exactly 1500us
    [ElectronicSpeedController.h, Wiiceiver.ino]
2014-05-28 ESC sync up again
2014-05-28 still tinkering with ESC sync
2014-05-29 More attempted ESC mucking
    changes the ESC init code, and some mods to Z-button handling. Z==no
    smoothing under throttle
2014-06-03 updating PCB slightly
    6-pin header was a little tight…
    [wiiceiver v1.brd, wiiceiver v1.sch]
2014-06-05 wow, a bug!
    found a legit bug. Nutty!
    [ElectronicSpeedController.h]
2014-06-10 resets wiiciever to "factory" default
    Running / loading this sketch will overwrite stored values for
    auto-cruise and nunchuck calibration, as if the chip were brand new.
    This is NOT a functioning wiiceiver!
    On success, both red and green lights will be lit. If one or both are
    not lit, something bad happened
    [factory_reset.ino]
2014-07-24 adaptive smoothing via floating ceiling
    uses a floating ceiling in smoother, for an adaptive smoothing. Also
    uses a program map: 5 programs (brakes, throttle, throttle + z, cruise,
    cruise + z) with 3 tunables in each (ceiling up, ceiling down,
    smoothness).
    Still needs some cleanup and a shitload of testing before RC-worthy
2014-07-25 beta-quality?
    smoothness & cruise are unsurprising. Throttle feels good.
2014-08-01 added a watchdog
    using the watchdog timer @ 250ms to (hopefully) catch a hardware glitch.
    [Chuck.h, Throttle.h, Wiiceiver.ino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]
2014-08-01 cleanup; Z == raw stick
    some more code cleanup, and updated Z throttle program to be 100% (no
    smoothing)
2014-08-03 watchdog cleanup
    more watchdog work; now an 8S timer in freakout / inactive mode, as
    there are many built-in delays while resyncing
2014-08-05 working on cruise resume
    adding some unfortunate complexity in CCR (check cruise return), to
    track intermediate states. This allows us to resume from cruise in a
    similar manner to acceleration, including a new “resume” smoothing
    program.
2014-08-08 adding an "Experimental" sketch
    not a branch, because Arduino :/
2014-08-09 stores & recalls history
    uses EEPROMAnything; probably should switch to EEPROMex…
2014-08-11 minor cleanup, including history
    no longer prints empty records in the history
    [Chuck.h, ElectronicSpeedController.h, Throttle.h]
2014-08-11 fixing a hilarious bug in auto-cruise
    the bug: dropping cruise DURING A (SLOW) RESUME would save the
    possibly-quite-slow “previous cruise speed”, possibly lower than the
    auto-cruise level. This is not intentional, as auto cruise should be
    the slowest possible cruise speed.
    also fattened the “cancel cruise” input range to 10%, I think touchy
    nunchucks are accidentally killing resume function :/
    [Throttle.h]
2014-09-11 incorporating phomann's V2 layout
    adding dual ESC support into the 1.x line and layout changes for Peter
    Homann’s awesome V2 SMD-based board.
    Backward compatible with v0 / v1 boards.
2014-09-13 1.2.1 -- dual ESC for v1 / v2 boards
    early V1 boards only have omen ESC port, but newer ones (which don’t
    otherwise self-identify) have it. Enable it for all of them, just in
    case.
2014-10-17 minor update for calibration function
    calibrates in 1s now, and more reliably
    also some minor changes to the schematic, fixing glitches
    [wiiceiver v1.brd, wiiceiver v1.sch]
2014-10-20 updated layouts
    new PCBS!
    [wiiceiver v2 new.brd, wiiceiver v2 new.sch]
2014-10-20 cleaning up
    [wiiceiver v2.brd, wiiceiver v2.sch]
2015-09-28 2.0 codebase, first drop
    includes full setup routine, cruise+drag brake control, new ESC sync
    routine, etc. A few minor nits, but down to fine-tuning at this point.
2015-10-15 moving *2.0 code to the 2.0 branch
    removing 1.3 and 2.0 from ‘master’ branch; it’s in 2.0
2016-02-23 prototypes
    Chuck is a handheld unit; Wiiceiver_Base (working title) is the
    corresponding receiver & servo driver.
